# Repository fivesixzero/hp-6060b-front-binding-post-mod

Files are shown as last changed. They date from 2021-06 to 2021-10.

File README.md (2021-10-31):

# hp-6060b-front-binding-post-mod

Front panel binding post modification for HP 6060B/6063B DC electronic load

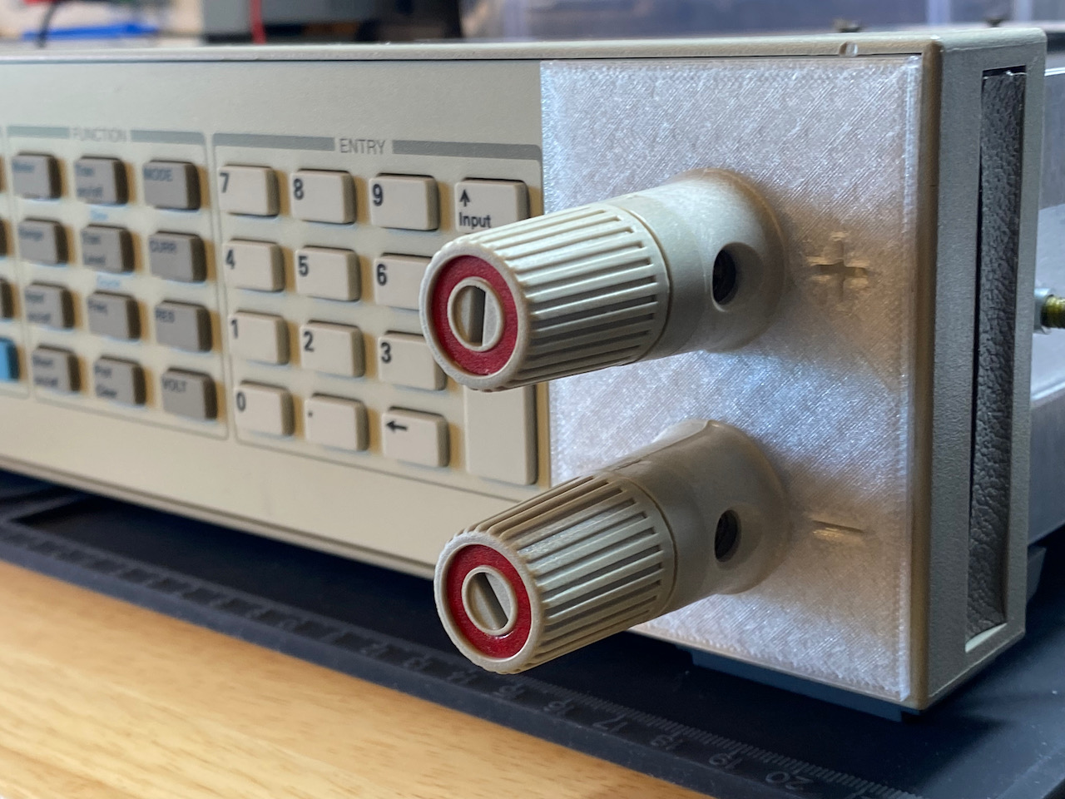
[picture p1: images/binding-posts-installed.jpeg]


## Obligatory Disclaimer

**Any modification of these devices is done at your own risk.**

_The 6060B and 6063B DC electronic loads are designed to sink a very large amount of power - 300W and 250W respectively. Any modifications to these units can produce very dangerous results if care is not taken to make sure that all additional or replaced parts meet or exceed the design requirements for the unit. When selecting all parts, even seemingly simple parts such as wire, be sure to verify that the new parts can **safely** carry voltages and current well beyond the ratings of the electronic load itself. Always do your own research and, if necessary, consult experts to assure that the parts you select and actions you undertake are safe._

## Overview

This project consists of an OpenSCAD script to create a 3D printable or CNC machinable panel to aid in mounting front panel binding posts on a Hewlett Packard/Agilent/Keysight `6060B` or `6063B` DC electronic load.

### Details

The HP `6060B`/`6063B` DC electronic load is a wonderful device for testing power supplies but for bench use the lack of front panel inputs can be a bit of a drag. This project aims to fix that by providing a 3D model for a mounting panel and documenting the process of installing front panel binding posts.

### Background

A relatively small number of `606xB` devices have `Option 020` installed. This option adds a second set of binding posts to the front of the device using a modified front panel and some additional parts. Thankfully, HP left behind some mounting holes in the panel's plastic for us to work with which will provide any intrepid maker with a solid starting point for modifying their own non-`Option 020` device to include a secondary set of easily accessible binding posts. The HP service manual also includes a lot of detail on the parts used by `Option 020`, providing the insight required to find parts that can meet or exceed the original specs.

### Additional Parts Required

Several other parts will be required in addition to the printed or machined mounting plate. Only the binding posts themselves are single-source and somewhat difficult to find.

#### Binding Posts and Binding Post Hardware

* 2x **Binding Post**, [HP P/N `1510-0134`](https://www.keysight.com/my/partDetail/1510-0134)
  * These are unique parts only used in Keysight's electronic loads so they may be hard to find.
  * Keysight sells these through their difficult-to-access parts system but can occasionally be found from various third party parts and surplus suppliers. I was lucky enough to spot a pair on [4gte.com](https://4gte.com/products/hp-agilent-1510-0134-binding-post-new/) while they were available.
* 2x **Hex Nut, M12x1.75, 6mm Height**, [HP P/N `0535-0020`](https://www.keysight.com/my/partDetail/0535-0020)
  * I used [this part from McMaster Carr](https://www.mcmaster.com/90710A130/).
  * As of mid-2021 I still have a bunch of spares, so send me an email if you're having a hard time finding them
* 2x **Washer, Curved, 13mm ID, 0.2mm Thick, Spring Steel**, [HP P/N `3050-1320`](https://www.keysight.com/my/partDetail/3050-1320)
  * I ended up using two washers from [this kit purchased from Amazon US](https://www.amazon.com/dp/B07QNLN43L). These washers were definitely not of the same grade as the factory washers on the rear panel ~~but they appear to be doing their job just fine with a bit of extra tightening~~. _edit: These didn't work out very well and I'd recommend more robust washers for this use._
  * The Amazon-purchased washers weren't up to par and "went flat" very quickly so I ordered [this part from McMaster Carr](https://www.mcmaster.com/catalog/127/3492) which appears to be almost identical to the thick, proper spring steel factory originals. After several weeks they're still doing their job, providing the consistent, springy pressure required to hold the posts and mounting plate in place.
* 2x **Machine Screw, M5x0.8, 12mm Length, Pan Head**, [HP P/N `0515-0155`](https://www.keysight.com/my/partDetail/0515-0155)
* 2x **Washer, Locking, External Tooth Type A, 5.3mm ID, 10m OD, 0.6mm Thick, Spring Steel**, [HP P/N `2190-0629`](https://www.keysight.com/my/partDetail/2190-0629)
  * For the above two parts I used [this part from McMaster Carr](https://www.mcmaster.com/90317A602/). This part has a pre-installed external-tooth washer that is very close to HP's specified washer part. Like the other parts, I have a bunch of spares so feel free to send an email if you have trouble finding them.

#### Cabling

In addition to the binding posts, some cabling will need to be created to attach to the interior rear binding post terminals. This cable needs to be _at least_ 8 AWG with an ampacity in excess of 60A. I ended up using some high-spec 8 AWG copper wire that I had left over from another project that can handle well over the 60A the 6060B is rated to sink.

Many affordable options exist under the label "battery cable" but be aware that many consumer-facing vendors of this type of thing do not specify ampacity and, if they do, that number could be misleading at best - ie, specifying ampacity at very low temps rather than the ~30-40c expected within a unit like this - or outright fabricated at worst.

The cable will need to be terminated on each end with a crimp lug that will fit an M8 bolt. Its important to select an appropriately sized lug and its equally important to crimp the lug solidly to assure that only minimal contact resistance is added at the connection.

I ended up using [these Würth Elektronik lugs from Digi-Key](https://www.digikey.com/en/products/detail/5580510/732-4295-ND/3844685) and they worked out great. Each crimp connection was protected with heat-shrink tubing to keep things clean and tidy.

## Usage Directions

There are a bunch of different ways to accomplish this mod. The optimal solution for your case will likely depend on the tools you have available. For instance, some people have used CNC machines to precisely cut out the binding post flange pattern in the front panel aluminum itself. Unfortunately, not all of us have access to high quality CNC systems. :)

At the very least this process would have been a lot easier with a drill press but, alas, one wasn't available to me so I did things by hand. It worked out but getting the step bit to end at just the right spot was a bit nerve wracking.

### Tools

* Center Punch
* Power Drill (or drill press)
* 2mm Carbide Bit
* Carbide Step Bit
* Metal files and/or de-burring tool
* Socket wrench with M12 socket
* Screwdriver with Pozidriv #2 bit
* Wire cutters and wire stripper
* Hammer crimper and hammer

### Printing The Panel

A few prototypes will likely be required to get the panel's dimensions to match your specific front panel. In my case, even after the initial dimensions were figured out, it took six prototype cycles to land on the right dimensions.

While prototyping, it can be useful to reduce the panel's model height to 1mm in the slicer to keep filament usage to a minimum.

If you haven't used OpenSCAD before don't worry, its not that difficult. Here's the process I've used to get a model out of OpenSCAD and into my slicer of choice.

1. Modify the variables to match measurements
2. Click "Render"
3. Click "Export to STL"
4. Open the exported STL in your slicer of choice

### Assembly Process

1. Remove the front panel of the `606xB`
2. Measure the the interior plastic mounting holes and mark their centers in the aluminum front panel with a center punch
3. Drill a starter hole from the interior side with a 2mm (or similar) bit
4. From the exterior side, use the step bit to gradually increase the hole's diameter to 17mm
5. File down or de-burr the freshly cut surfaces as needed
6. Lay the printed panel on the front panel then, if required, tune the variables in the OpenSCAD model to fit
7. Reattach the front panel to the `606xB`
8. Attach cable to connect the front and rear post assemblies
9. Re-assemble the `606xB`

Once that's complete, power up the unit and run through the relevant verification procedures listed in the manual to make sure that everything's operating as expected.

## Reference Links

* <https://literature.cdn.keysight.com/litweb/pdf/5951-2828.pdf>
  * The 6060B/6063B Service Manual includes a lot of information on the parts used by `Option 020` as well as a layout diagram showing how the cabling is run.
* <https://www.twam.info/electronics/test-equipment/upgrading-hp-6060b-dc-electronic-load-with-front-binding-posts>
  * Great post by Tobias Müller describing his process for installing front panel binding posts. This was a very valuable resource while researching this project.

## License

This project has been licensed by its creator under the Creative Commons CC0 1.0 Universal license. See the `LICENSE` file for more details.

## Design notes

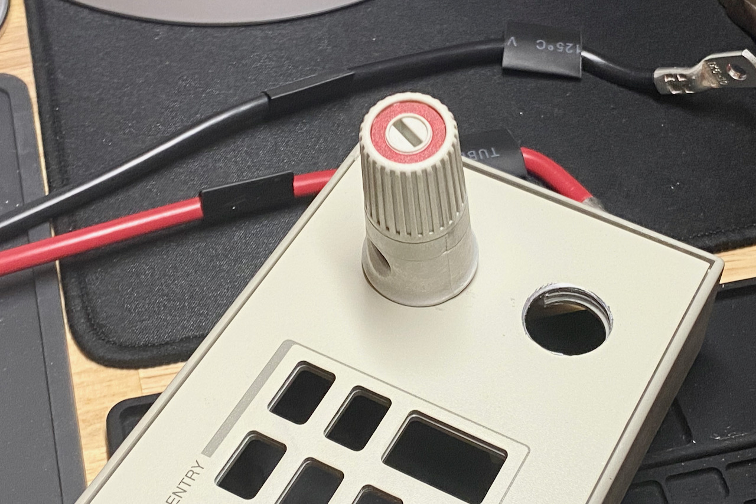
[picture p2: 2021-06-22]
images/binding-posts-in-progress.jpeg

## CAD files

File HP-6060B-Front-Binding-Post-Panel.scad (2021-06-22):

/*
 * HP 6060B/6063B Front Binding Post Modification Plate
 * 
 * This OpenSCAD file creates a model for a plate to use for mounting binding posts to the front panel of a Hewlett Packard, Agilent or Keysight 6060B or 6063B Electronic Load that does not currently have Option 020 (front panel posts) installed. This mod makes use of existing holes on the front panel assembly that are used for Option 020 on devices that have this option installed.
 * 
 * In addition to this plate, other parts are required to complete this modification. Drilling out of the front panel aluminum plate will also be required. Specifically, this plate is built to fit the retention flanges on the factory binding posts, HP P/N 1510-0134. See the readme file in the source repository for more details.
 *
 * https://github.com/fivesixzero/hp-6060b-front-binding-posts-mod
 */

// The default values here allow the panel to fit well enough within the front panel of my HP 6060B (S/N prefix 3436A) no glue or additional mounting hardware is required beyond simply tightening the post mounting bolts. Your specific panel may vary, however, so these variables can be tuned to fit your specific panel without too much trouble.

// This model was printed on a Prusa MINI+ with Prusament Clear PETG. The print gcode was sliced by Prusaslicer at "0.2mm QUALITY"/Prusament PETG default settings. Your printer or slicer settings are likely to cause slight tolerance shifts that may require additional tuning of these variables to enable a snug fit.

// Customizable Varaibles
/*[ Plate Properties]*/
plate_height = 84.025;
plate_width = 59;
plate_depth = 3;

/*[ Post Properties]*/
dia_main = 17.1; 
dia_p1 = 3.6;
dia_p2 = 2.6;

/*[ Post Center Offsets]*/
post_1_offset = -20; // Post 1's position above/below to center line 
post_2_offset = 15;  // Post 2's position above/below to center line

/* [ Symbol Properties]*/
symbol_size_ratio = 0.49; // Ratio of symbol size to binding post diameter
symbol_line_width = 1.5; // Width of symbol lines

/*[]*/
post_1_center = [post_1_offset, 0, -.5]; // Offsetting post positions on Z
post_2_center = [post_2_offset, 0, -.5]; // axis to assure full plate cutouts

module __customizer_limit__() {} // End Customizr vars

// Global Variables
$fs = 0.02;  // Set facet size to 0.02mm for relatively high arc resolution
$fa = 2.5;   // Set max facet angle to 2.5 degrees for relatively high arc resolution

h_post = plate_depth * 2; // Make sure that post cutouts are tall enough to fully intersect with plate

// Individual parts used to build plate and cutout
module plate(width, height, depth) {
    translate([-(width/2), -(height/2), 0]) cube([width, height, depth]);
}

module binding_post(d_main, d_p1, d_p2, h_main=10, h_p=5) {
    r_main = d_main * 0.5;
    cylinder(h_main, r_main, r_main);
    
    r_p1 = d_p1 * 0.5;
    translate([-(r_main), 0, 0]) cylinder(h_p, r_p1, r_p1);
    translate([(r_main), 0, 0]) cylinder(h_p, r_p1, r_p1);
    
    r_p2 = d_p2 * 0.5;
    translate([0, -(r_main), 0]) cylinder(h_p, r_p2, r_p2);
    translate([0, (r_main), 0]) cylinder(h_p, r_p2, r_p2);
}

module sym_positive(length, height=4, line_width=1.5) {
    union() {
        translate([-(length * 0.5), -(line_width * 0.5), 0]) cube([length, line_width, height]);
        translate([-(line_width * 0.5), -(length * 0.5), 0]) cube([line_width, length, height]);
    }
}

module sym_negative(length, height=4, line_width=1.5) {
    translate([-(length * 0.5), -(line_width * 0.5), 0]) cube([length, line_width, height]);
}

// Build the plate from the above parts
difference() {
    // Create flat plate
    color("grey")  plate(plate_height, plate_width, plate_depth);
    
    // Cut out binding post mounting holes
    translate(post_1_center) binding_post(dia_main, dia_p1, dia_p2, h_post, h_post);
    translate(post_2_center) binding_post(dia_main, dia_p1, dia_p2, h_post, h_post);
    
    // Cut out positive polarity symbols
    translate([post_1_offset, (dia_main + (dia_main/7)), -0.1]) rotate([0, 0, 90]) sym_negative(dia_main * symbol_size_ratio);
    translate([post_1_offset, -(dia_main + (dia_main/7)), -0.1]) rotate([0, 0, 90]) sym_negative(dia_main * symbol_size_ratio);
    
    // Cut out negative polarity symbols
    translate([post_2_offset, (dia_main + (dia_main/7)), -0.1]) sym_positive(dia_main * symbol_size_ratio);
    translate([post_2_offset, -(dia_main + (dia_main/7)), -0.1]) sym_positive(dia_main * symbol_size_ratio);
}

// Written by Erik Hess <erik@noisedamage.com> on 2021/06/21
//
// To the extent possible under law, the author(s) have dedicated all copyright and related and neighboring rights to this software to the public domain worldwide. This software is distributed without any warranty.
//
// You should have received a copy of the CC0 Public Domain Dedication along with this software.
// If not, see <http://creativecommons.org/publicdomain/zero/1.0/>.

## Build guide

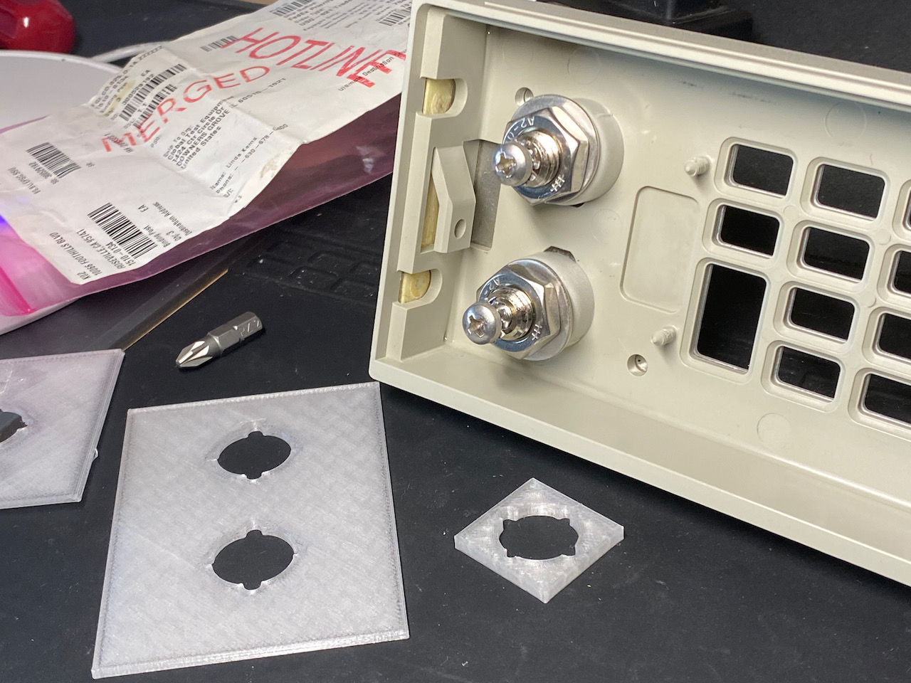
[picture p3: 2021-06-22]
images/binding-posts-installed-interior.jpeg

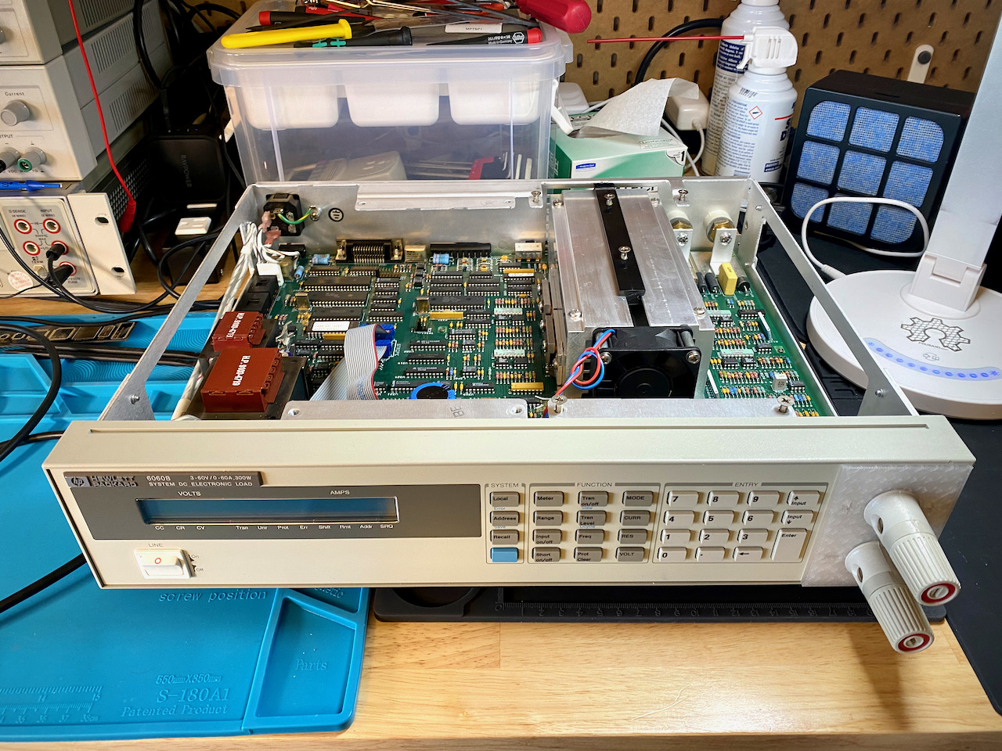
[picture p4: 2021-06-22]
images/binding-posts-installed-whole-device.jpeg

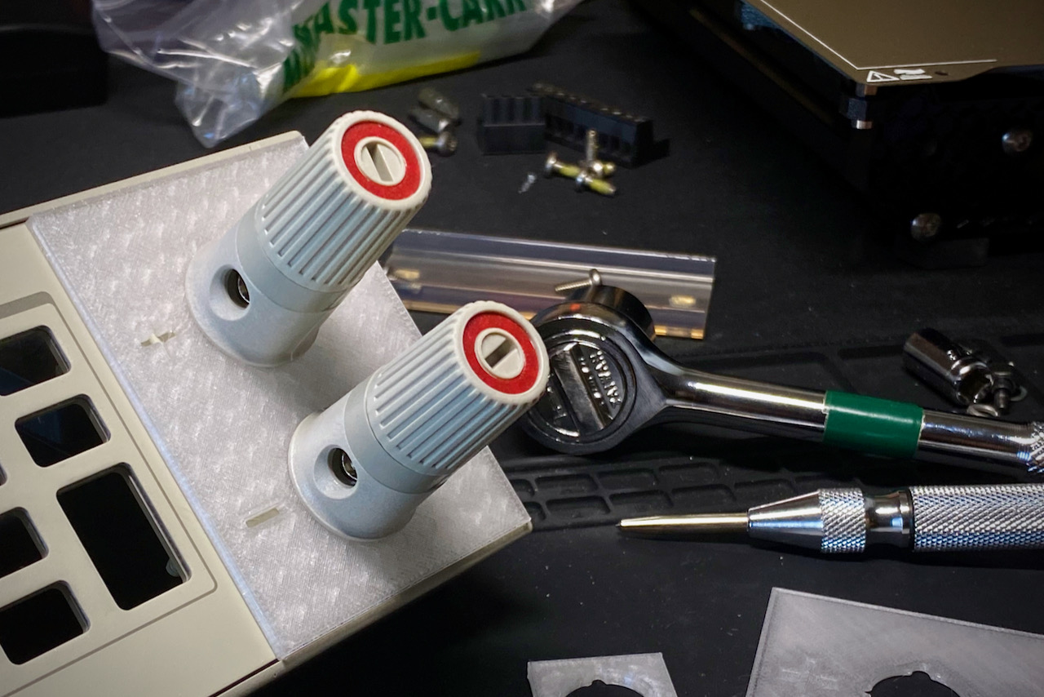
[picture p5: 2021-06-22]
images/binding-posts-installed-on-panel.jpeg
